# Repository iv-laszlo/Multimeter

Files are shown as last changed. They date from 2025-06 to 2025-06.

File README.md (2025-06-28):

# Multimeter

This project is a custom-built Digital Multimeter developed by a student team, as part of an academic project. The device is capable of measuring voltage, current, and resistance, and was designed from the ground up using embedded systems and custom PCB design.

Features

    Measures DC voltage, current, resistance, and temperature

    Built using a microcontroller with analog signal processing

    Designed in KiCad for schematic and PCB layout

    Fully functional firmware written in C/C++

    Simple and intuitive user interface

Tools & Technologies

    Microcontroller: Aruino Nano [ATmega328P]

    KiCad: PCB and schematic design

    C/C++: Firmware development

    Multimeter principles: Analog signal acquisition, ADC, display interface

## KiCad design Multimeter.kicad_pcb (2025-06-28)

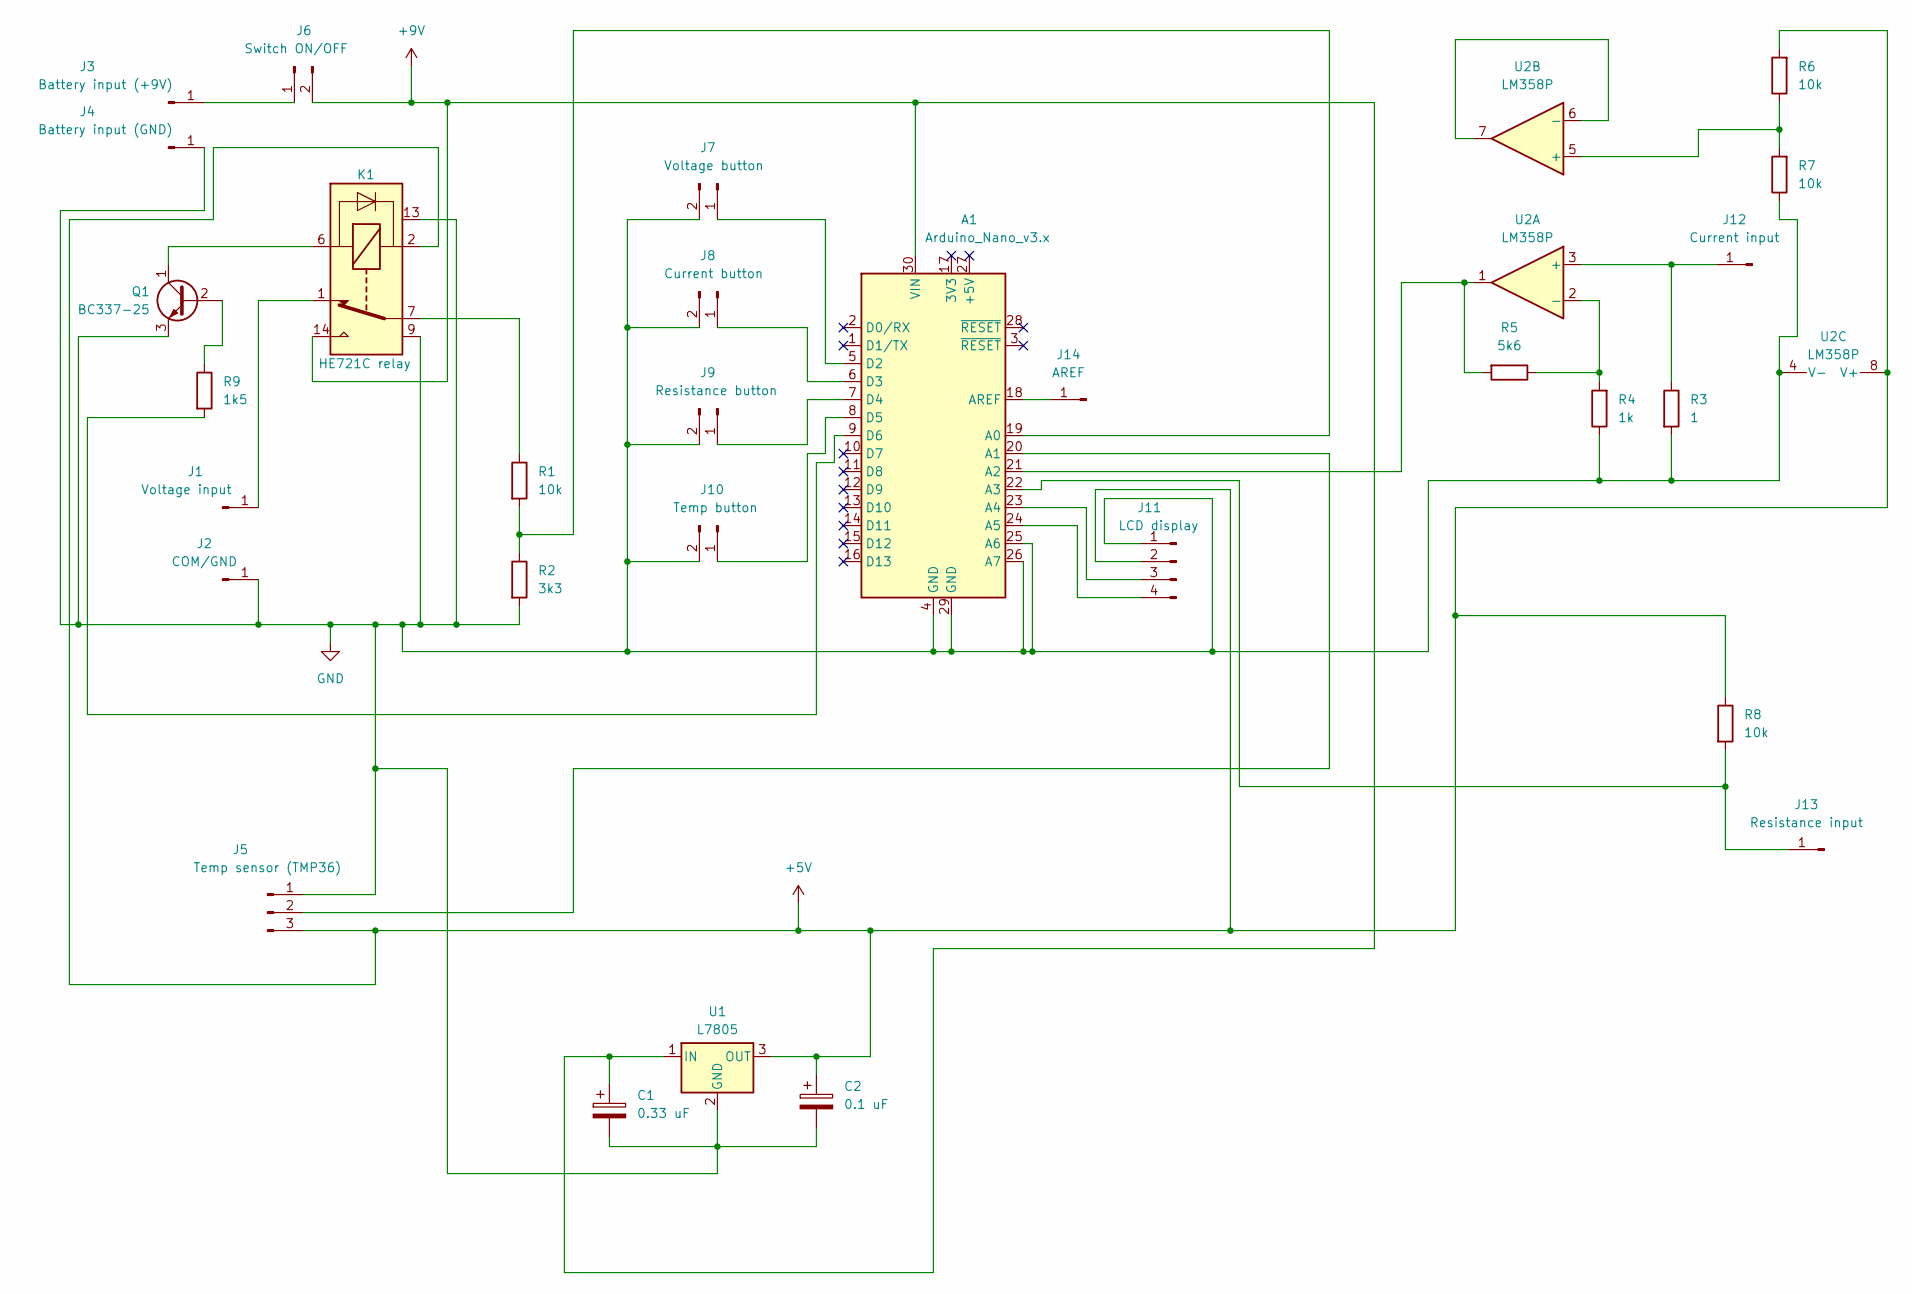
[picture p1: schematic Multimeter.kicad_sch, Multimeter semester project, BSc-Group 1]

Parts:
A1: Arduino_Nano_v3.x; Arduino_Nano
C1: 0.33 uF; CP_Radial_Tantal_D4.5mm_P2.50mm
C2: 0.1 uF; CP_Radial_Tantal_D4.5mm_P2.50mm
J1: Voltage input; PinHeader_1x01_P2.54mm_Vertical
J2: COM/GND; PinHeader_1x01_P2.54mm_Vertical
J3: Battery input (+9V); PinHeader_1x01_P2.54mm_Vertical
J4: Battery input (GND); PinHeader_1x01_P2.54mm_Vertical
J5: Temp sensor (TMP36); PinHeader_1x03_P2.54mm_Vertical
J6: Switch ON/OFF; PinHeader_1x02_P2.54mm_Vertical
J7: Voltage button; PinHeader_1x02_P2.54mm_Vertical
J8: Current button; PinHeader_1x02_P2.54mm_Vertical
J9: Resistance button; PinHeader_1x02_P2.54mm_Vertical
J10: Temp button; PinHeader_1x02_P2.54mm_Vertical
J11: LCD display; PinHeader_1x04_P2.54mm_Vertical
J12: Current input; PinHeader_1x01_P2.54mm_Vertical
J13: Resistance input; PinHeader_1x01_P2.54mm_Vertical
J14: AREF; PinHeader_1x01_P2.54mm_Vertical
K1: HE721C relay; HE700
Q1: BC337-25; TO-92_Inline_Wide
R1, R6, R7, R8: 10k; R_Axial_DIN0207_L6.3mm_D2.5mm_P10.16mm_Horizontal
R2: 3k3; R_Axial_DIN0207_L6.3mm_D2.5mm_P10.16mm_Horizontal
R3: 1; R_Axial_DIN0207_L6.3mm_D2.5mm_P10.16mm_Horizontal
R4: 1k; R_Axial_DIN0207_L6.3mm_D2.5mm_P10.16mm_Horizontal
R5: 5k6; R_Axial_DIN0207_L6.3mm_D2.5mm_P10.16mm_Horizontal
R9: 1k5; R_Axial_DIN0207_L6.3mm_D2.5mm_P10.16mm_Horizontal
U1: L7805; TO-220-3_Vertical
U2: LM358P; DIP-8_W7.62mm

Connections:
+5V: C2.1, J5.3, J11.2, K1.2, R6.2, R8.1, U1.3 (OUT), U2.8 (V+)
+9V: A1.30 (VIN), C1.1, J6.2, K1.14, U1.1 (IN)
GND: A1.4 (GND), A1.25 (A6), A1.26 (A7), A1.29 (GND), C1.2, C2.2, J2.1, J4.1, J5.1, J7.2, J8.2, J9.2, J10.2, J11.1, K1.9, K1.13, Q1.3 (E), R2.2, R3.2, R4.1, R7.1, U1.2 (GND), U2.4 (V-)
unnamed: A1.19 (A0), R1.2, R2.1
unnamed: A1.20 (A1), J5.2
unnamed: A1.21 (A2), R5.2, U2.1
unnamed: A1.22 (A3), J13.1, R8.2
unnamed: A1.23 (A4), J11.3
unnamed: A1.24 (A5), J11.4
unnamed: A1.18 (AREF), J14.1
unnamed: A1.5 (D2), J7.1
unnamed: A1.6 (D3), J8.1
unnamed: A1.7 (D4), J9.1
unnamed: A1.8 (D5), J10.1
unnamed: A1.9 (D6), R9.2
unnamed: J1.1, K1.1
unnamed: J3.1, J6.1
unnamed: J12.1, R3.1, U2.3 (+)
unnamed: K1.7, K1.8, R1.1
unnamed: Q1.2 (B), R9.1
unnamed: K1.6, Q1.1 (C)
unnamed: R4.2, R5.1, U2.2 (-)
unnamed: R6.1, R7.2, U2.5 (+)
unnamed: U2.6 (-), U2.7

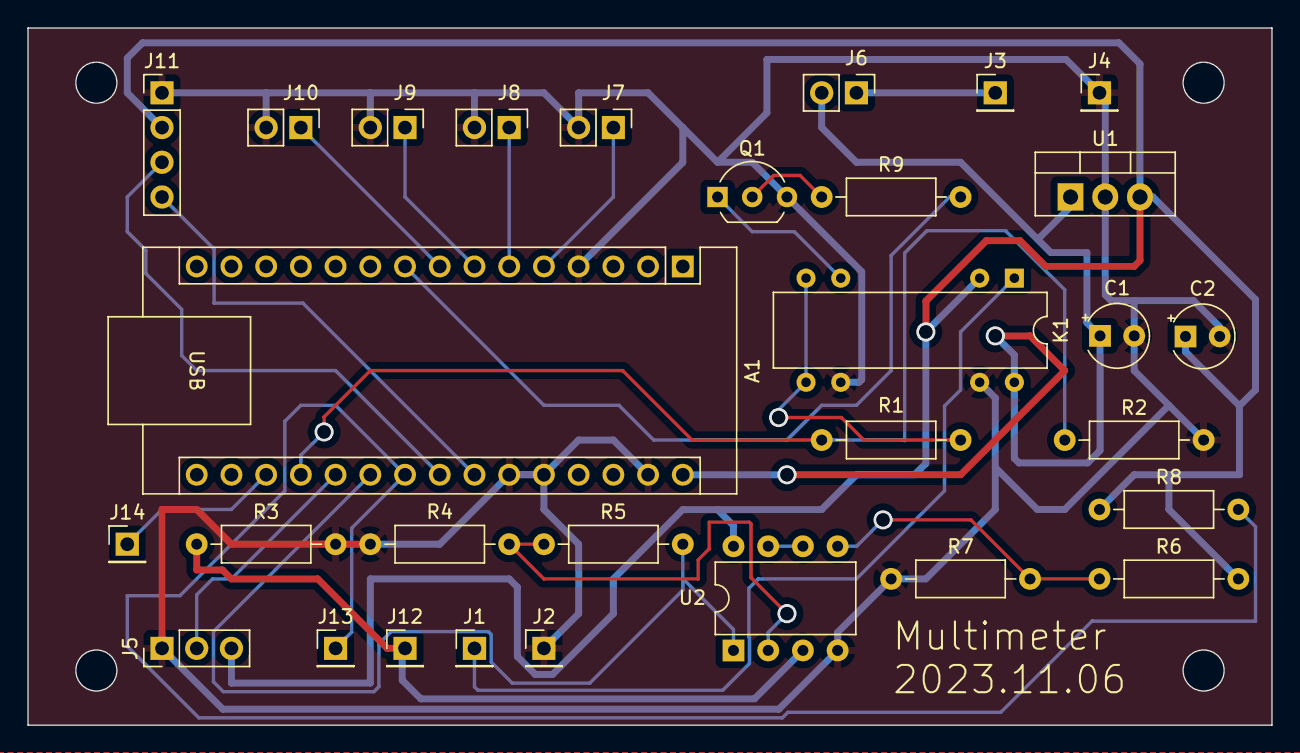
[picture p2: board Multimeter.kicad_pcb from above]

Board: 2 copper layers, 91.0 x 51.0 mm, 30 parts (0 on the bottom side), 24 nets.

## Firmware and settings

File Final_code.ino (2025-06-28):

#include <LiquidCrystal_I2C.h>

//defining sensor pins
const int VOLTMETER = A0; //voltmeter input pin
const int TEMPERATURE = A1; //temperature sensor input pin
const int CURRENTMETER = A2; //currentmeter input pin
const int RESISTANCEMETER = A3; //resistancemeter input pin

//defining button pins
const int VOLT_BUTTON = 2; //voltmeter button
const int CURRENT_BUTTON = 3; //currentmeter button
const int RES_BUTTON = 4; //resistancemeter button
const int TEMP_BUTTON = 5; //temperature sensor button
const int RELAY = 6; //relay switch pin

//defining unused pins as input with pullup resistors
const int PIN_PD7 = 7; //unused pin as input pullup resistor
const int PIN_PB0 = 8; //unused pin as input pullup resistor
const int PIN_PB1 = 9; //unused pin as input pullup resistor
const int PIN_PB2 = 10; //unused pin as input pullup resistor
const int PIN_PB3 = 11; //unused pin as input pullup resistor
const int PIN_PB4 = 12; //unused pin as input pullup resistor

//defining other constants
const float V_REF = 6.06; //reference voltage level
const float SHUNT_RES = 1.30; //reference shunt resistor R3
const float REF_RES = 9930.00; //serial resistor R8 for the resistancemeter
const int MENU_PERIOD = 500; //disable first button for 500 ms
const float IDEAL_LEVEL = 7.5; //defining minimum level of voltage on the battery

//defining constant resistor values
const float R1 = 9920.00;
const float R2 = 3270.00;
const float R4 = 993.00;
const float R5 = 5560.00;

//global variables
int flag = 0;
float result;
unsigned long menu_timer = 0;


LiquidCrystal_I2C lcd(0x27, 4, 20); //0x27 address of the LCD in hexa


float calculate_voltage()
{
  float resistor_ratio;
  int sensorValue = 0;
  float voltage;
  float v;
  resistor_ratio = (R2 / (R1 + R2));
  for (int i = 0; i < 20 ; i++) //calculating the average analog voltage by taking 20 measurments
    {
    sensorValue += analogRead(VOLTMETER);
    delay(3);
    }
  voltage = sensorValue * V_REF / (1023.00 * 20.00);
  v = voltage / resistor_ratio; //calculate the voltage
  return v;
}

float calculate_current()
{
  float current_gain;
  float voltage;
  int sensorValue = 0;
  float c;
  current_gain = 1+(R5/R4);
  for (int i = 0; i < 20 ; i++) //calculating the average analog voltage by taking 20 measurments
    {
    sensorValue += analogRead(CURRENTMETER);
    delay(3);
    }
  voltage = sensorValue * V_REF / (1023.00 * current_gain * 20.00); // Convert to voltage
  c = voltage * 1000.00 / SHUNT_RES; //calculate the current in mA
  return c;
}

float calculate_resistance()
{
  float voltage;
  float r;
  int sensorValue = 0;
  for (int i = 0; i < 20 ; i++) //calculating the average analog voltage by taking 20 measurments
    {
    sensorValue += analogRead(RESISTANCEMETER);
    delay(3);
    }
  voltage = sensorValue * V_REF / (1023.00 * 20.00); // Convert to voltage
  r = voltage * REF_RES / (V_REF - voltage); //calculate the resistance
  return r;
}

float temperature_measurement()
{
  float tempc; //variable to store temperature in degree Celsius
  int sensorValue = 0;
  for (int i = 0; i < 20 ; i++) //calculating the average analog voltage by taking 20 measurments
    {
    sensorValue += analogRead(TEMPERATURE);
    delay(3);
    }
  tempc = (sensorValue * V_REF) / (1023.00 * 20.00 * 0.01) - 68.00; //storing value in Degree Celsius
  return tempc;
}

float battery()
{
  float battery_level;
  digitalWrite(RELAY, HIGH);
  battery_level = calculate_voltage();
  digitalWrite(RELAY, LOW);
  return battery_level;
}

void menu()
{
  lcd.clear();
  lcd.setCursor(0,0);lcd.print("Press 1 - Temp."); //display choice
  lcd.setCursor(0,1);lcd.print("Press 2 - Resistance"); //display choice
  lcd.setCursor(0,2);lcd.print("Press 3 - Current"); //display choice
  lcd.setCursor(0,3);lcd.print("Press 4 - Voltage"); //display choice
}


void setup()
{
  //initializing the LCD  
  lcd.init(); //initializing LCD
  lcd.backlight(); //turning the backlight on for the LCD

  //initializing sensor pins
  pinMode(VOLTMETER, INPUT); //configuring sensor pin as input for voltmeter
  pinMode(TEMPERATURE, INPUT); //configuring sensor pin as input for temperature sensor
  pinMode(CURRENTMETER, INPUT); //configuring sensor pin as input for currentmeter
  pinMode(RESISTANCEMETER, INPUT); //configuring sensor pin as input for resistancemeter
  pinMode(RELAY, OUTPUT); //configuring pin as output for relay

  //initializing button pins
  pinMode(VOLT_BUTTON, INPUT_PULLUP); //configuring button pin as input with pullup resistor for voltmeter
  pinMode(CURRENT_BUTTON, INPUT_PULLUP); //configuring button pin as input with pullup resistor for currentmeter
  pinMode(RES_BUTTON, INPUT_PULLUP); //configuring button pin as input with pullup resistor for resistancemeter
  pinMode(TEMP_BUTTON, INPUT_PULLUP); //configuring button pin as input with pullup resistor for temperature sensor

  //initializing unused pins as input with pullup resistors
  pinMode(PIN_PD7, INPUT_PULLUP); //configuring pin as input with pullup resistor
  pinMode(PIN_PB0, INPUT_PULLUP); //configuring pin as input with pullup resistor
  pinMode(PIN_PB1, INPUT_PULLUP); //configuring pin as input with pullup resistor
  pinMode(PIN_PB2, INPUT_PULLUP); //configuring pin as input with pullup resistor
  pinMode(PIN_PB3, INPUT_PULLUP); //configuring pin as input with pullup resistor
  pinMode(PIN_PB4, INPUT_PULLUP); //configuring pin as input with pullup resistor

  //welcome message
  lcd.setCursor(7,1);
  lcd.print("WELCOME!");
  lcd.setCursor(0, 2);
  lcd.print("BSC GROUP MULTIMETER");
  delay(3000);
  lcd.clear();
  delay(1000);
  
  //battery level check
  if(battery() >= IDEAL_LEVEL)
  {
    lcd.setCursor(5,1);
    lcd.print("BATTERY OK");
    delay(3000);
    lcd.clear();
    delay(1000);
  }
  else
  {
    lcd.setCursor(5,1);
    lcd.print("BATTERY LOW");
    delay(3000);
    lcd.clear();
    delay(1000);
  }

  menu();
}


void loop()
{
  if(digitalRead(TEMP_BUTTON) == LOW)
  {
    if(millis() >= menu_timer)
    {  
      if(flag != 0)
      {
        menu();
        flag = 0;
      }
      else
      {
        flag = 1;
        lcd.clear();
      }
      menu_timer = millis() + MENU_PERIOD;
    }
  }
  if(digitalRead(RES_BUTTON) == LOW)
  {
    if(flag == 0)
    {
      flag = 2;
      lcd.clear();
    }
  }
  if(digitalRead(CURRENT_BUTTON) == LOW)
  {
    if(flag == 0)
    {
      flag = 3;
      lcd.clear();
    }
  }
  if(digitalRead(VOLT_BUTTON) == LOW)
  {
    if(flag == 0)
    {
      flag = 4;
      lcd.clear();
    }
  }
  if((digitalRead(RES_BUTTON) == LOW) && (digitalRead(CURRENT_BUTTON) == LOW))
  {
    if((flag == 2) || (flag == 3))
    {
      flag = 10;
      lcd.clear();
    }
  }

  switch (flag)
  {
    case 1:
      result = temperature_measurement();
      lcd.setCursor(0,0);
      lcd.print("Press 1 - Menu");
      // Display the measured temperature on the LCD
      lcd.setCursor(0, 2);
      lcd.print("Temperature (");
      lcd.print((char)223);
      lcd.print("C):");
      lcd.setCursor(0, 3);
      lcd.print("                    ");
      lcd.setCursor(0, 3);
      lcd.print(result); // Display temperature
    break;

    case 2:
      result = calculate_resistance();
      lcd.setCursor(0,0);
      lcd.print("Press 1 - Menu");
      // Display the measured resistance on the LCD
      lcd.setCursor(0, 2);
      lcd.print("Resistance (Ohm):");
      lcd.setCursor(0, 3);
      lcd.print("                    ");
      lcd.setCursor(0, 3);
      if(result > 150000)
      {
        lcd.print("inf");
      }
      else
      {
        lcd.print(result); // Display resistance
      }
    break;

    case 3:
      result = calculate_current();
      lcd.setCursor(0,0);
      lcd.print("Press 1 - Menu");
      // Display the measured current on the LCD
      lcd.setCursor(0, 2);
      lcd.print("Current (mA):");
      lcd.setCursor(0, 3);
      lcd.print("                    ");
      lcd.setCursor(0, 3);
      lcd.print(result); // Display current
    break;

    case 4:
      result = calculate_voltage();
      lcd.setCursor(0,0);
      lcd.print("Press 1 - Menu");
      // Display the measured voltage on the LCD
      lcd.setCursor(0, 2);
      lcd.print("Voltage (V):");
      lcd.setCursor(0, 3);
      lcd.print("                    ");
      lcd.setCursor(0, 3);
      lcd.print(result); // Display voltage
    break;

    case 10:
      result = battery();
      lcd.setCursor(0,0);
      lcd.print("Press 1 - Menu");
      // Display the measured voltage of the battery on the LCD
      lcd.setCursor(0, 2);
      lcd.print("Battery level (V):");
      lcd.setCursor(0, 3);
      lcd.print("                    ");
      lcd.setCursor(0, 3);
      lcd.print(result); // Display voltage of the battery
    break;
  }
}
